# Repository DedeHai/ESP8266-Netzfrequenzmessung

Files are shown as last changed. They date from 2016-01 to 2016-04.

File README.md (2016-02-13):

# ESP8266-Netzfrequenzmessung
Measure 50Hz power grid frequency deviation using an ESP8266.

For discussions about this visit forum.netzsin.us

License:
Software under MIT license
Hardware under Creative Commons 4.0 license: CC-BY-NC-SA

#Mutatio Hardware 
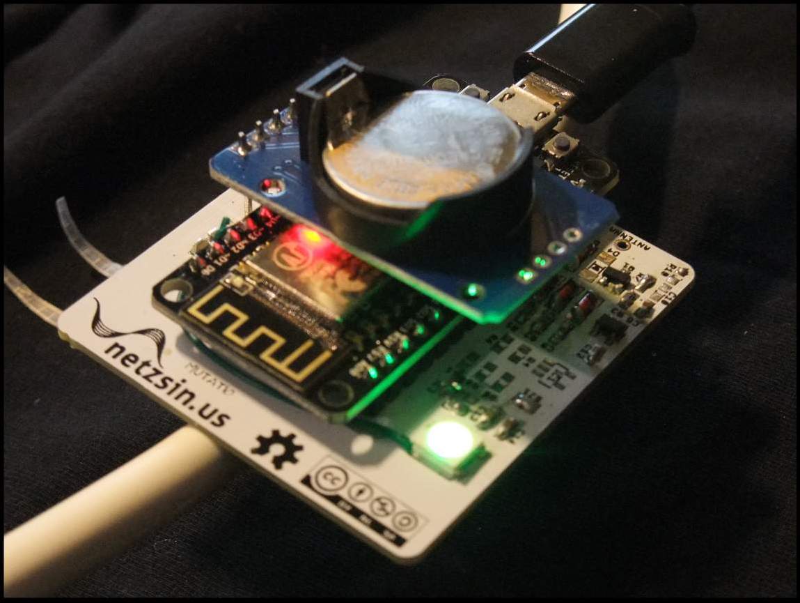
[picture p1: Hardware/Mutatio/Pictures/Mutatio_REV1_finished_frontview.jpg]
Mutatio


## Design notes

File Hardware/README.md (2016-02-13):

#Mutatio: grid frequency tracker
part of the netzsin.us project

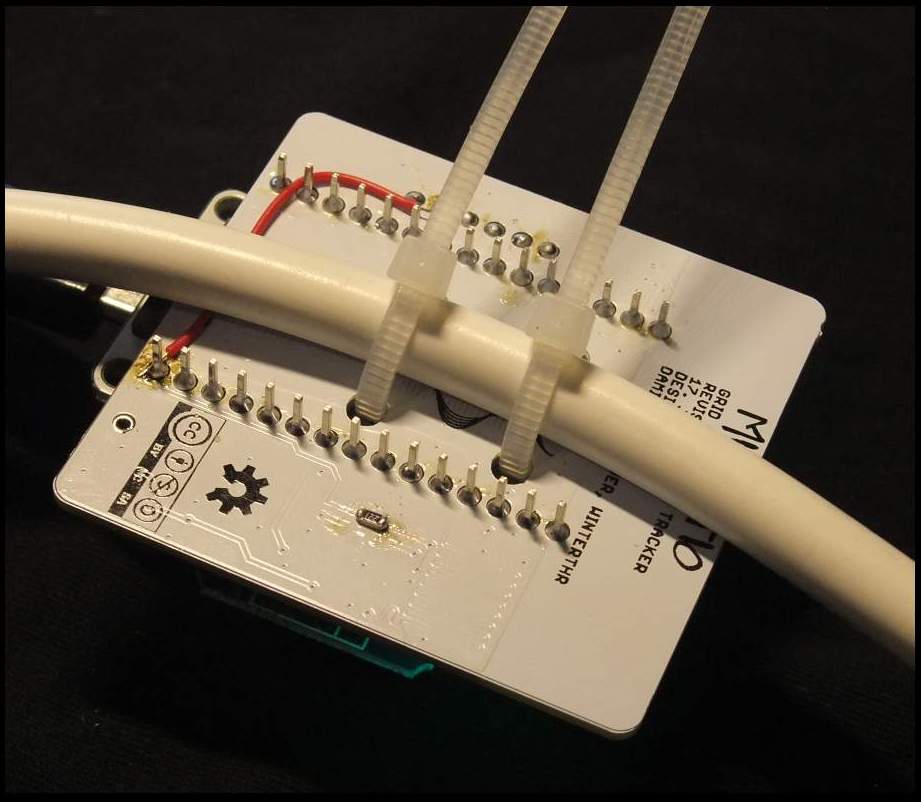
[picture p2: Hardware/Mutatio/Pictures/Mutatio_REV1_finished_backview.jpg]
backview
Mutatio |

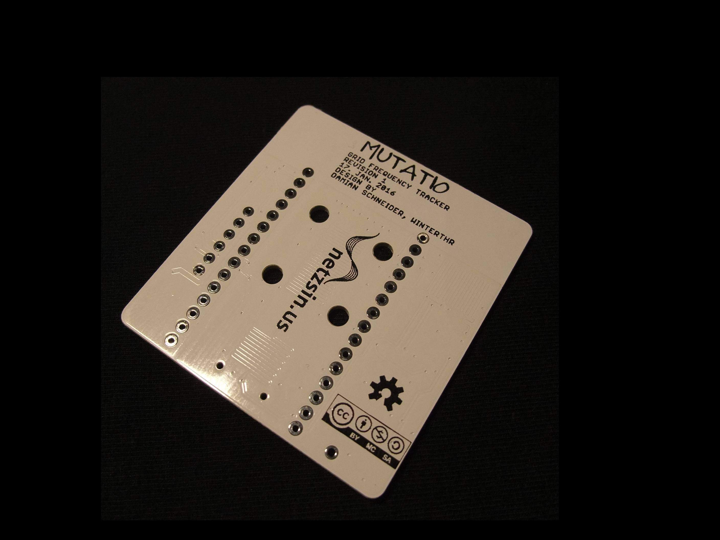
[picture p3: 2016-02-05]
Hardware/Mutatio/Pictures/Mutatio_REV1_PCB_back.jpg

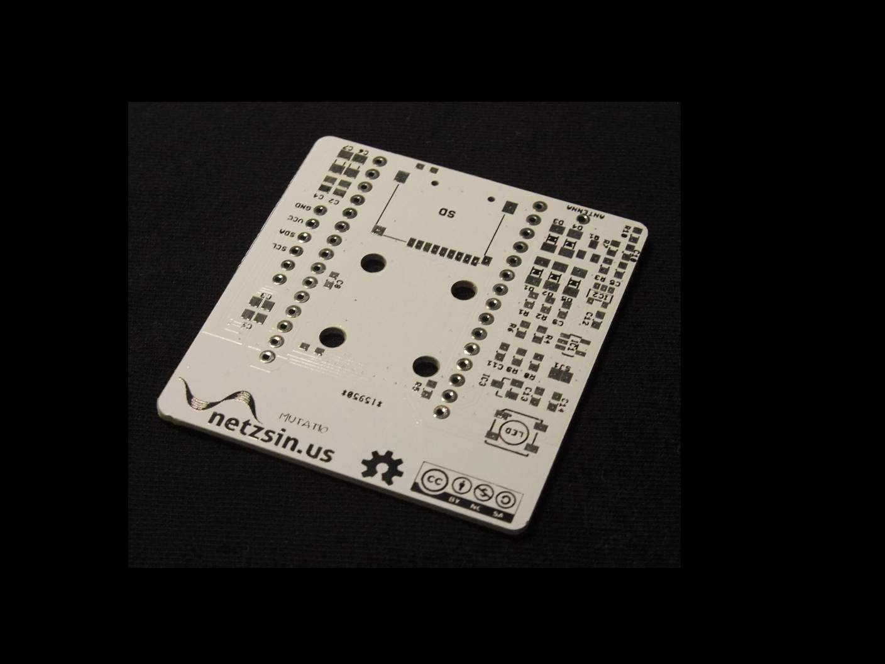
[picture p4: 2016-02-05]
Hardware/Mutatio/Pictures/Mutatio_REV1_PCB_front.jpg

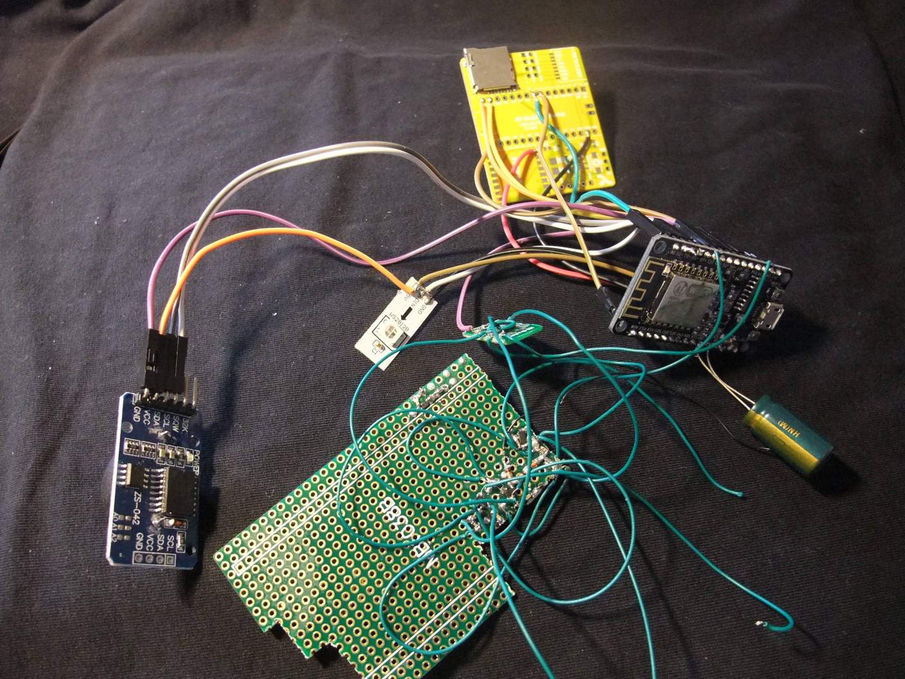
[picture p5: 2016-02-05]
Hardware/Mutatio/Pictures/prototype.jpg

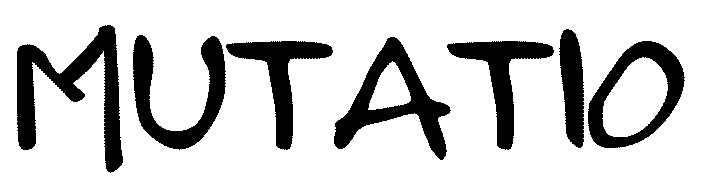
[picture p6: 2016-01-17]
Hardware/Mutatio/mutatio-font-rufscript-bw.bmp

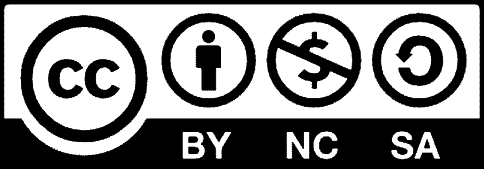
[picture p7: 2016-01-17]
Hardware/Mutatio/cc-by-nc-sa.bmp

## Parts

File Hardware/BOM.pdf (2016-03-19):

Tabelle1

Seite 1

### Mutatio BOM

Part description | Part | Cost | Source
NodeMCU (V1) | - | 6.16 € | Banggood (http://www.banggood.com/Geekcreit-Doit-NodeMcu-Lua-ESP8266-ESP-12E-WIFI-Development-Board-p-985891.htm)
RTC Module, DS3231 (Optional, track time without internet) | - | 0.90 € | Banggood (http://www.banggood.com/DS3231-AT24C32-IIC-High-Precision-Real-Time-Clock-Module-For-Arduino-p-81066.html)
NFET 2SK3018 | Q1 | 0.05 € Ebay/Aliexpress
Schmitt trigger SN74LVC1G14DBVR | IC2 | 0.07 € Ebay/Aliexpress
100uF 1206 Capacitor | C6, C7 | 0.10 € Ebay/Aliexpress
47uF 0805 Capacitor | C1, C2, C3, C4 | 0.10 € Ebay/Aliexpress
WS2812B Color LED | LED | 0.12 € Ebay/Aliexpress
22uF 0603 Capacitor | C9, C13, C14 | 0.05 € Ebay/Aliexpress
1uF 0603 Capacitor | C5 | 0.01 € Ebay/Aliexpress
100nF 0603 Capacitor | C8, C12 | 0.01 € Ebay/Aliexpress
1N4148 Diode | D1, D2, D3 | 0.02 € Ebay/Aliexpress
MicroSD Socket | - | 0.10 € Ebay/Aliexpress
51k Resistor, 0603 | R1, R2, R5 | 0.01 € Digikey
100k Resistor, 0603 | R2 | 0.01 € Digikey
1k Resistor, 0603 | R3 | 0.01 € Digikey
PCB | - | 1.40 € Elecrow
7.72 €

Additional Parts are untested (OpAmp circuit)
For datalogging, an SD card is needed (~3MB per day)

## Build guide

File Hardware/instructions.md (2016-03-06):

#Mutatio Instructions

##Uploading Firmware
Install the Arduino IDE (1.6.7 or later) and add the ESP8266 extension by following the instructions given [here](https://github.com/esp8266/Arduino). I prefer the manual cloning method over the boards manager since it works better for me. If you get any weird compiler errors, try installing manually.
The Mutatio firmware only uses two external libraries. One can be installed using the Arduino Library Manager. Install the Adafruit NeoPixel from the Manager and manually install the RTC library that can be found [here](https://github.com/Makuna/Rtc).
After installing the libraries the code should compile without errors.
**Important: the frequency signal MUST be present to upload code, seems to be a hardware bug.**

To upload the code to the Mutatio, set the board settings to:

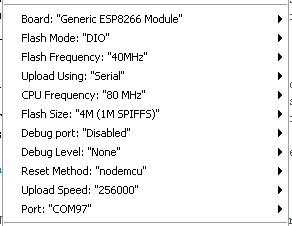
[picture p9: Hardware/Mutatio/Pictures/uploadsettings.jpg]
settings


Note: after setting up the WiFi connection also over the air uploading using WiFi (OTA update) instead of serial can be used.

##Setup
The first thing should be to get a proper signal. For testing, a 50cm (or longer) cable can be connected to the external antenna point marked 'Antenna' on the board. I use wire wrap wire but any wire will do. The Mutatio sometimes does not boot properly if there is no signal present, it is unknown why.
Open the serial port using the Arduino IDE serial monitor or any other serial monitor. I prefer 'Realterm' since it runs more stable on Windows than the Arduino monitor. Setting the Baudrate to 115200 and then resetting the board (press reset button, repeat if not booting) there should be debug output on the serial. The first two lines of gibberish are debug info from the ESP8266 chip itself and can be ignored.
Then the output should look like this:
```
sldœŸ|Œlà|Œläb|Žƒä›{›cŒcŒòggžl'nœãìcpä$slslxògàƒd„œcoâ|lŒŒ‡ÇcŒógnçd„d`˜ggl ns
››oƒŒl`r’“gƒ„d`üƒoœ                                                             
Mutatio grid frequency tracker, part of netzsin.us project                      
Reading Configuration                                                           
Configurarion Found!                                                            
connecting to MYSSID                                                            
WIFI not available: NO SSID AVAILBLE  
```
Next the Mutatio needs to be configured. This is done through the setup page. To access it, press and hold the 'Flash' button for three seconds, then release it. The LED color turns purple indicating that the accesspoint is ready. Connect your computer's WiFi to the accesspoint named 'Mutatio-XXXX' with the default password '11111111'. Open any web browser and go to '192.168.4.1'. The config page will show. Enter your routers SSID and password. As a default, DHCP is used to obtain an IP. For a static IP you can also disable DHCP and enter the connection addresses manually.
The second part of the page lets you configure the Mutatio hardware and server settings. Put checks if you are using an SD card or the real time clock (RTC).
Once the Mutatio is connected to your local WiFi the configuration page can also be accessed by entering the Muatio's local IP address: check the serial output for the IP or assign a static IP. If you have mDNS support on your computer (install apple's bonjour service) you can also access it through the address 'http://mutatio.local/'.

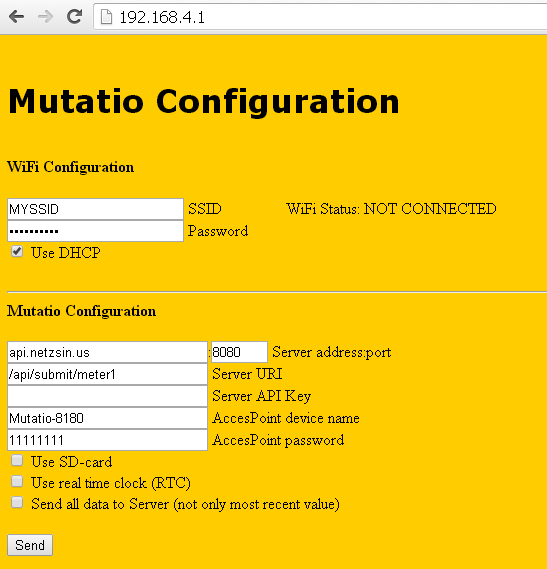
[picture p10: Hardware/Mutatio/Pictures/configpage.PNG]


##LED status colors
The LED colors indicate the status:
- **Red**: no frequency signal available: check antenna and bring a power cable close to it. If using the on board antenna: make sure the Mutatio is mounted well on the power cable as shown in the [photo](Hardware/Mutatio/Pictures/Mutatio_REV1_finished_backview.jpg).
- blinking **Yellow**: WiFi disconnected: after booting it takes up to 20s to connect
- blinking **Blue**: SD card access failed: check if SD card is present and FAT formatted 
- bright purple: access point running, 5 minute timeout 
- dim purple: OTA update in progress. Do not disconnect power or update will fail and may require re-upload through USB
- during normal operation the LED indicates the grid frequency: from blue (-60mHz) to green (0mHz) to red (+60mHz)

##Problem solving
####Frequency Signal
To check proper operation use the serial monitor. If the frequency signal is available and the time is properly set (either from the RTC or from an NTP server) there will be one measurement value displayed each second. It looks like this
```
-24.17  -24.08  75      @UTC 16:29:08.447  
```
The first number is the frequency offset calculated. The second value is the moving average over all measurement values, including all raw values. This should be very close or even identical to the first value on a good signal. The third value is a quality indicator: it shows how many measurement points out of 100 values are regarded as valid: to calculate the frequency 100 values are measured and averaged. Outliers are discarded as noise. If this number is lower than 50 the input signal is too noisy. Try a shorter antenna and bring it as close as possible to the power cable: a 15cm antenna wrapped around the cable works nicely but the best signal is obtained from the onboard antenna. Anything above 80 will give good values but if the antenna is properly tuned values above 95 can be achieved.
A good and stable power supply is *very* important. A USB from a PC or a Server is usually a good choice. A USB power supply can also work, but it needs to be of good quality. Here is a graph showing the measurement with different powersupplies:

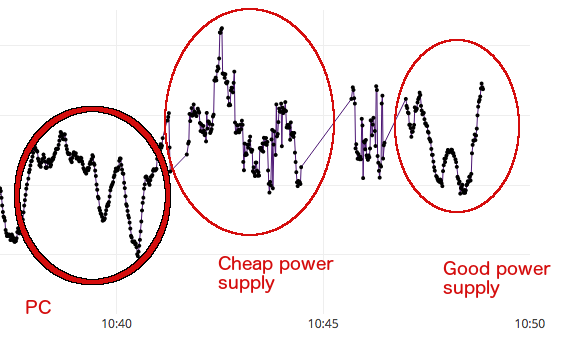
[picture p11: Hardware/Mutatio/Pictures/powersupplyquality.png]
signal vs powersupply


####Time
The time is constantly checked against a NTP server ('pool.ntp.org' by default). If the connection is too slow (average ping > 30ms) an accurate time sync is not possible. The accepted latancy can be changed in the firmware but it is not recommended since it leads to time jitter. To do so change 
````
#define ALLOWEDROUNDTRIPDELAY 30
```
in NTP_Time.h to a higher number.

To change the time server (or server pool) edit the string 
```
const char* ntpServerName = "pool.ntp.org";
```
also in in NTP_Time.h

The RTC is automatically synchronized with the NTP time every few hours. The RTC has a time keeping accuracy of ±2ppm.

####Server 
The data is sent out to a server every second. The server address (or IP) and the URI as well as the API-key can be changed on the configuration page.

There is an option on the configuration page to send out all values instead of always sending the latest one only. On a slow connection this can lead to a data jam since all unsent data is first kept in RAM and then saved to the SD card (if available, data is discarded otherwise). The Mutatio tries to sendout the oldest value first and works its way to the latest value as fast as possible. **NOTE: This mode is currently not supported by the defluxiod server software.**

In normal sending mode only the latest value is sent. If the server connection fails, the data is lost (but is still logged to the SD card if available). If the server connection always fails, check if the server address is set correctly. To see the data sent to the server and the server's response on the serial monitor, uncomment these lines in sendtoserver.h:
```
 // Serial.print(header);
 // Serial.print(jsonstring);
 
 // Serial.println(line); //uncomment this line to see servers response on serial
```

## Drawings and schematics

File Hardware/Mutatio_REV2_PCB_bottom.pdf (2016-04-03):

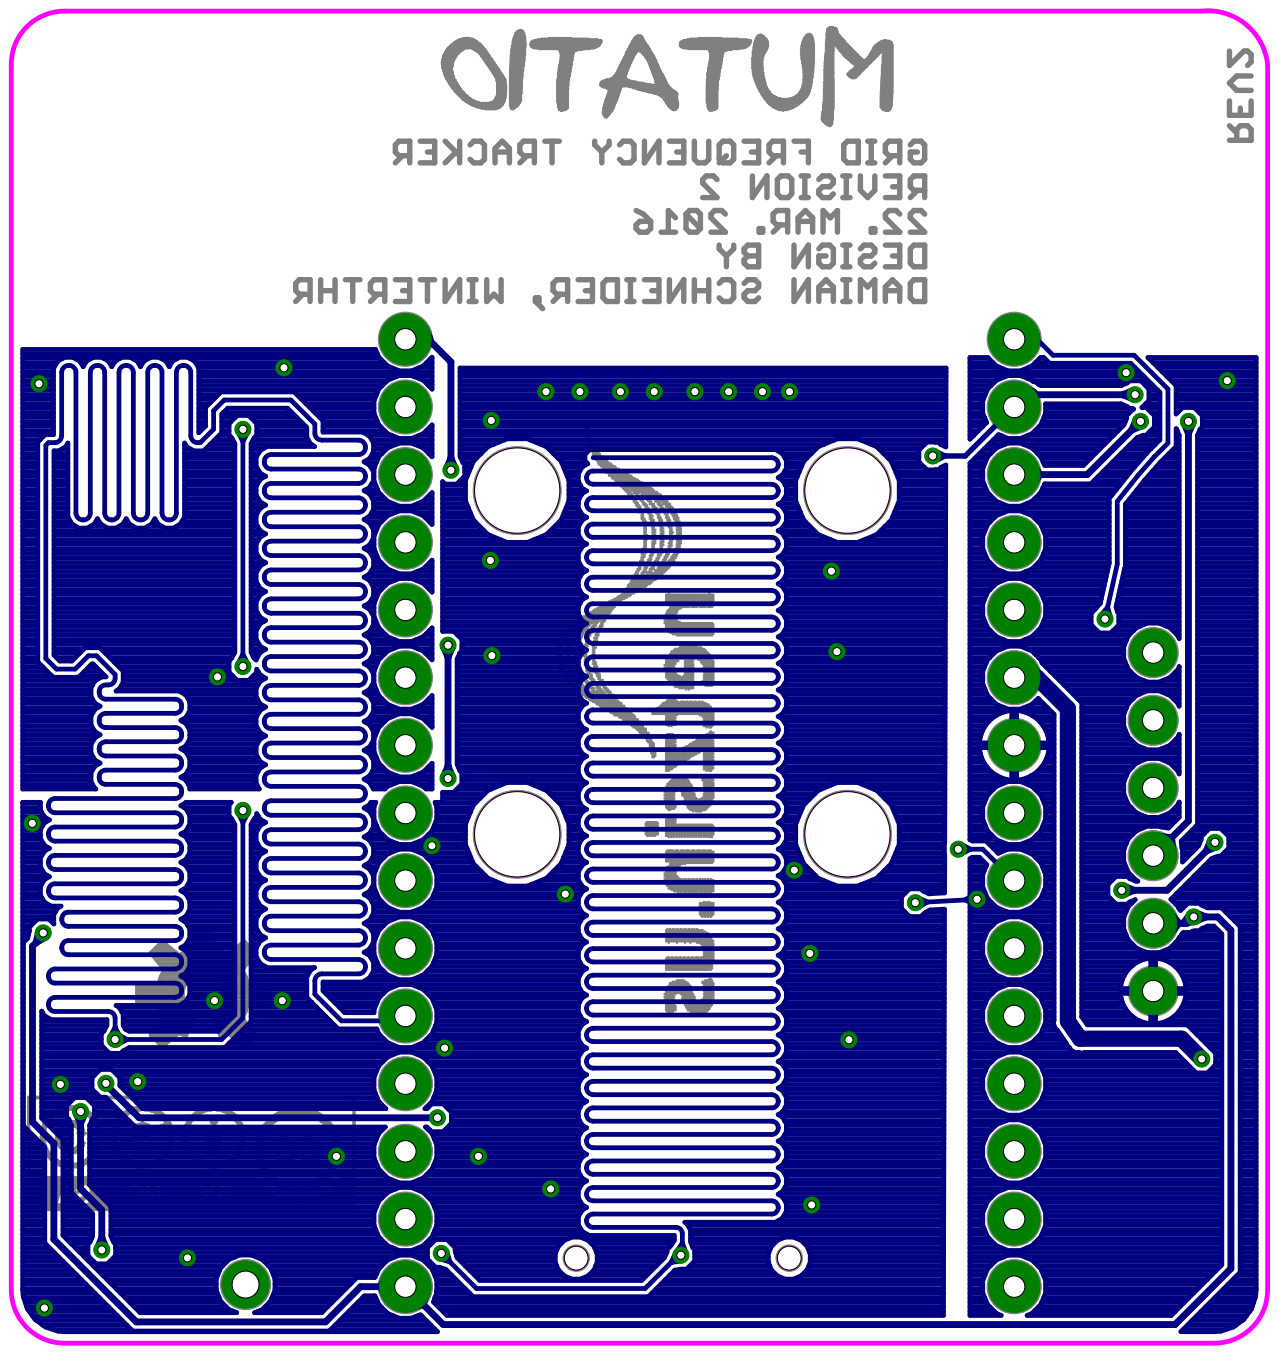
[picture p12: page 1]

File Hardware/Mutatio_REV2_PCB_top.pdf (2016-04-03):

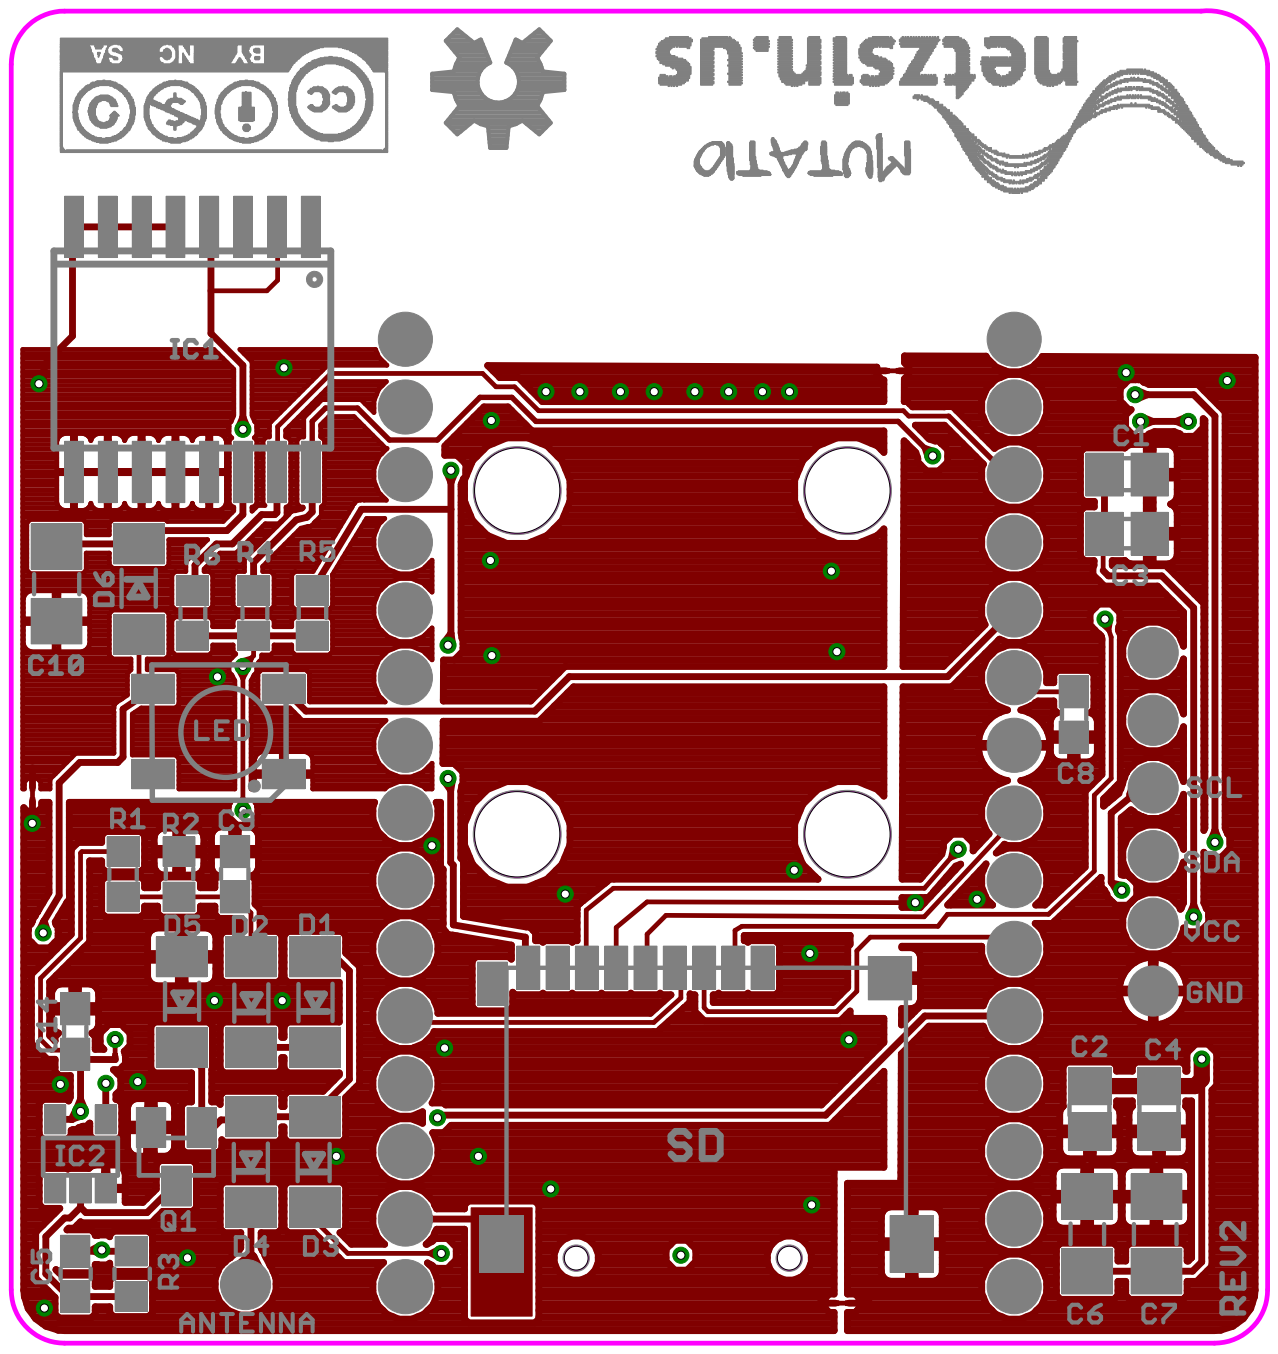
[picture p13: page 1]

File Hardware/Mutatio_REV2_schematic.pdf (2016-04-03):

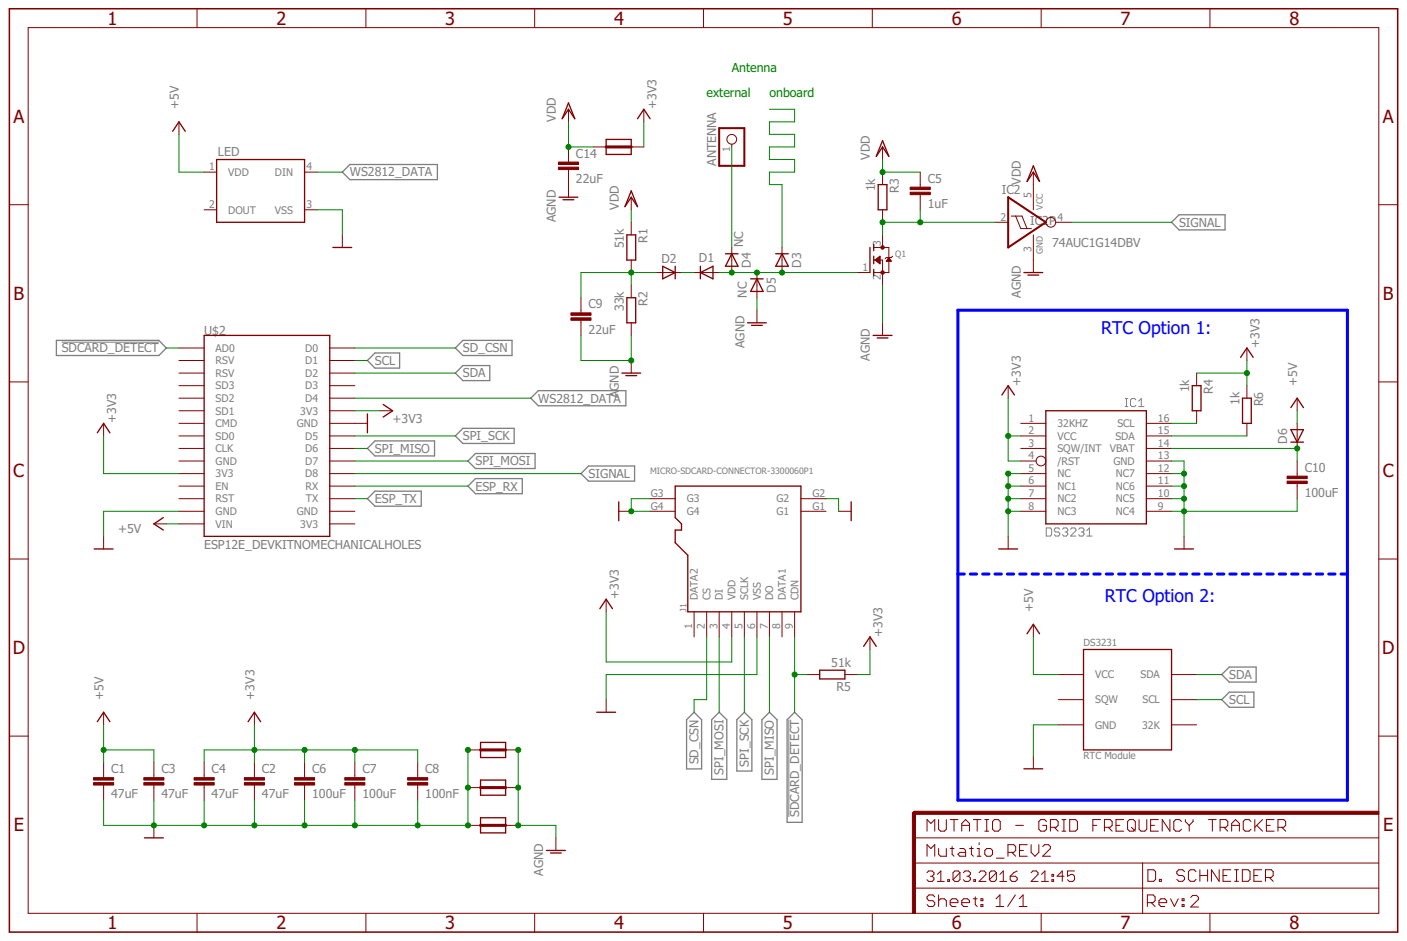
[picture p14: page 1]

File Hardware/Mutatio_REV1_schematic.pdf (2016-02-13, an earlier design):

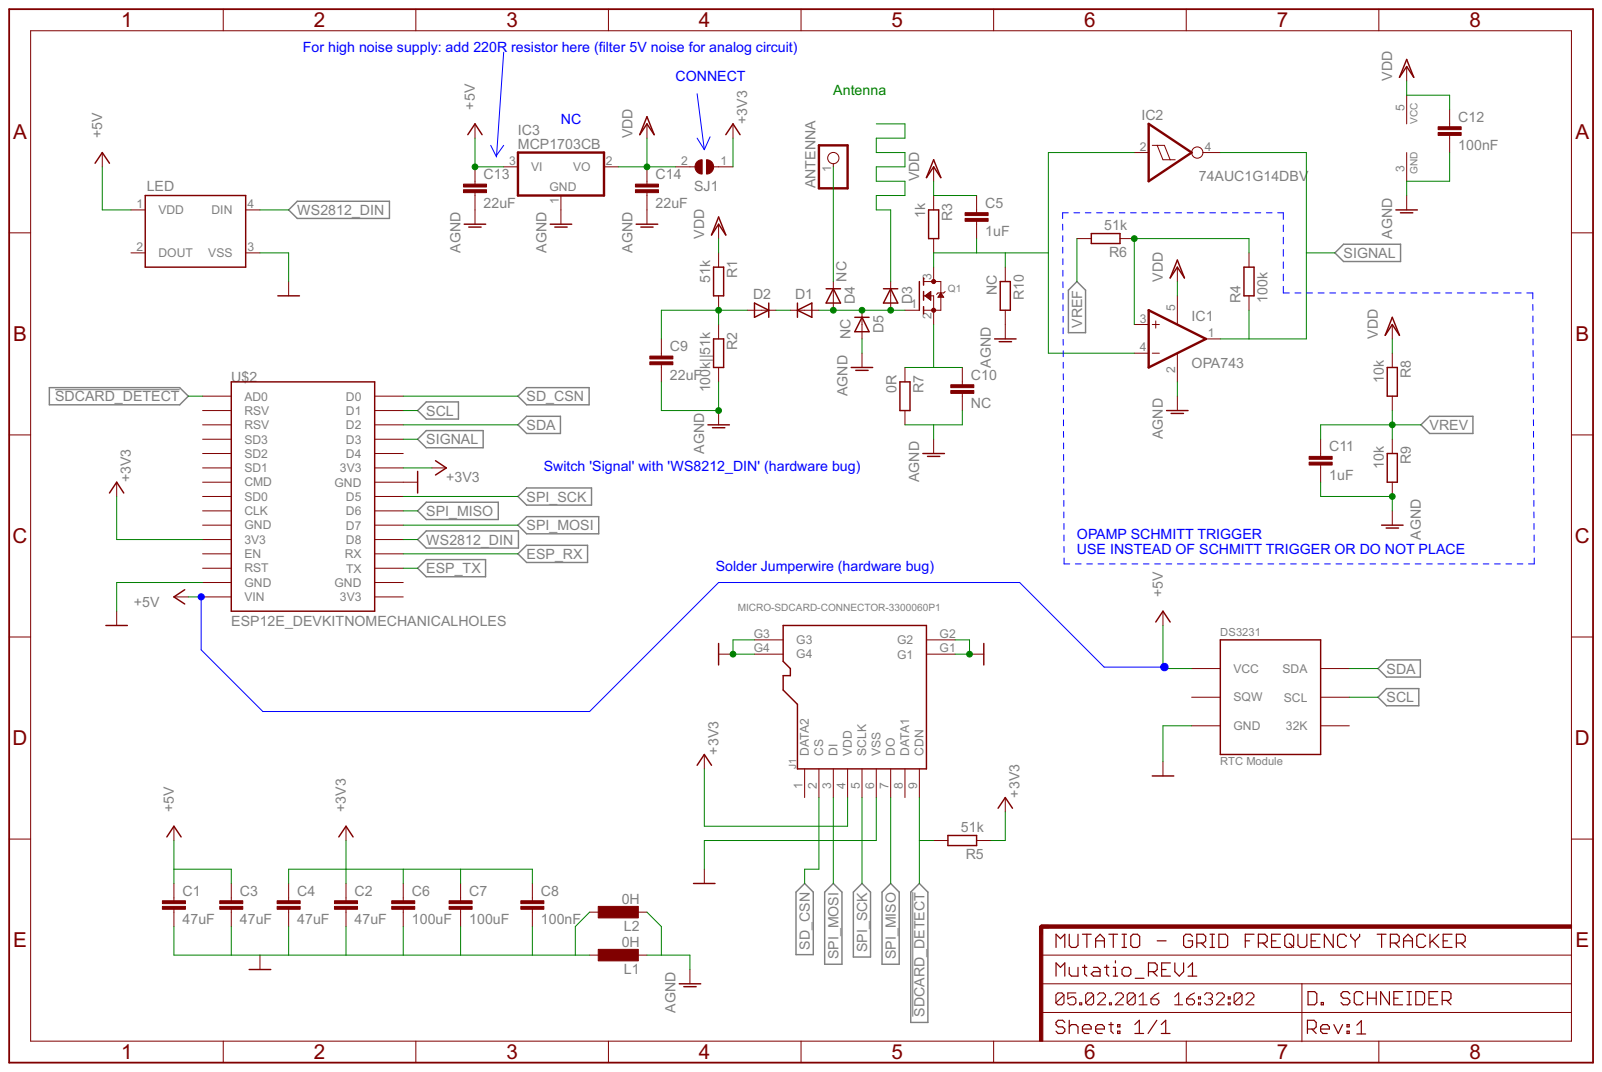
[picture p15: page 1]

Antenna For high noise supply: add 220R resistor here (filter 5V noise for analog circuit)

Switch 'Signal' with 'WS8212_DIN' (hardware bug)

OPAMP SCHMITT TRIGGER
USE INSTEAD OF SCHMITT TRIGGER OR DO NOT PLACE

Solder Jumperwire (hardware bug)

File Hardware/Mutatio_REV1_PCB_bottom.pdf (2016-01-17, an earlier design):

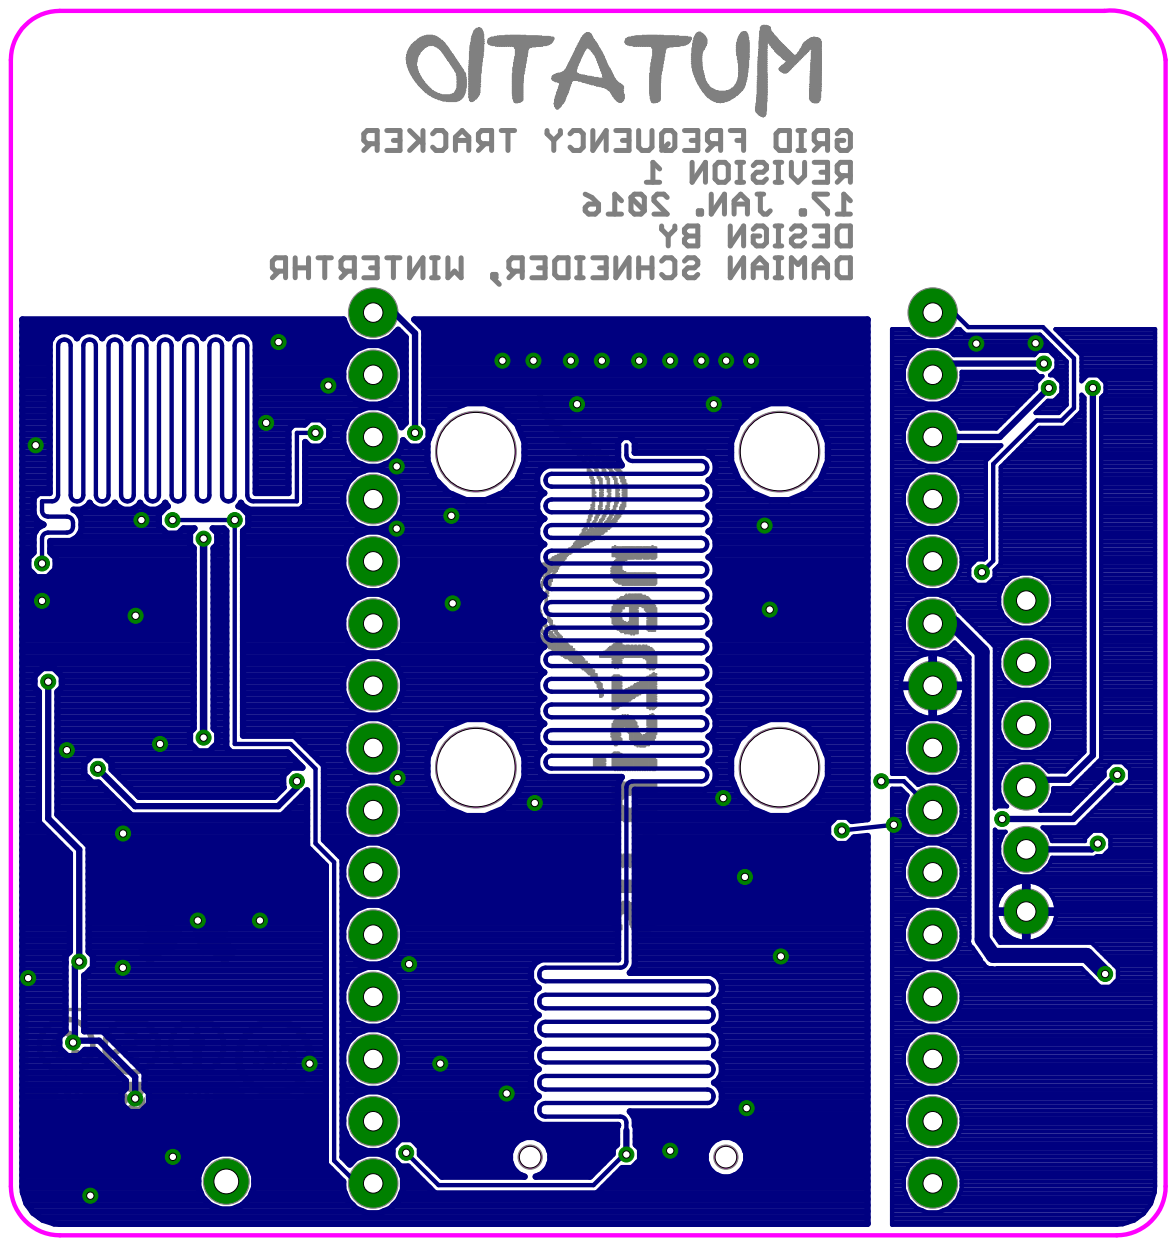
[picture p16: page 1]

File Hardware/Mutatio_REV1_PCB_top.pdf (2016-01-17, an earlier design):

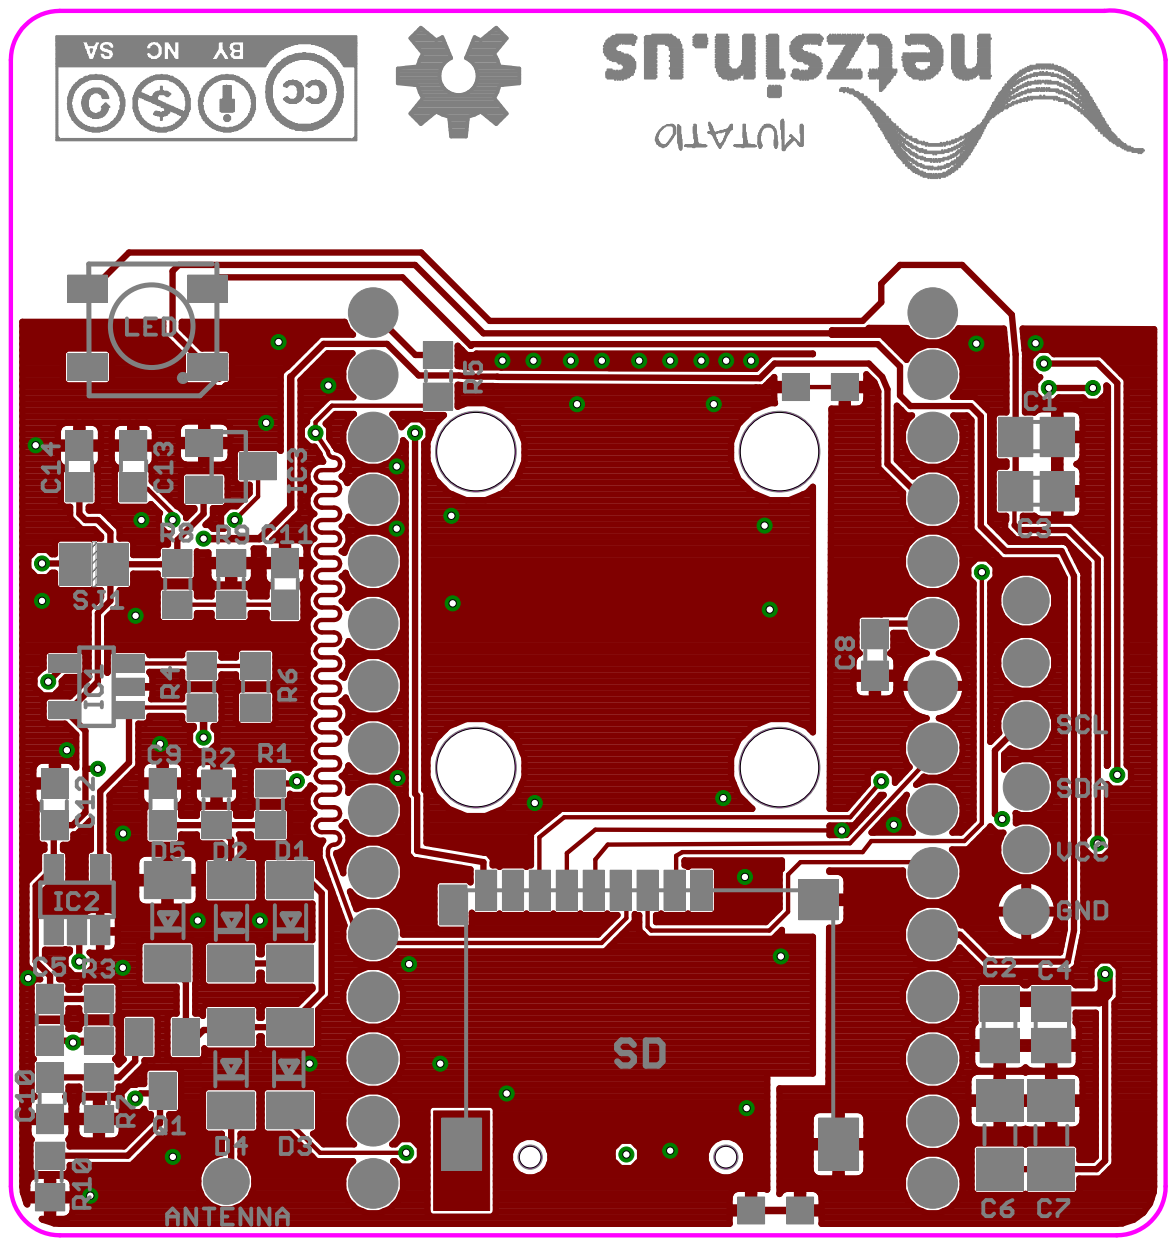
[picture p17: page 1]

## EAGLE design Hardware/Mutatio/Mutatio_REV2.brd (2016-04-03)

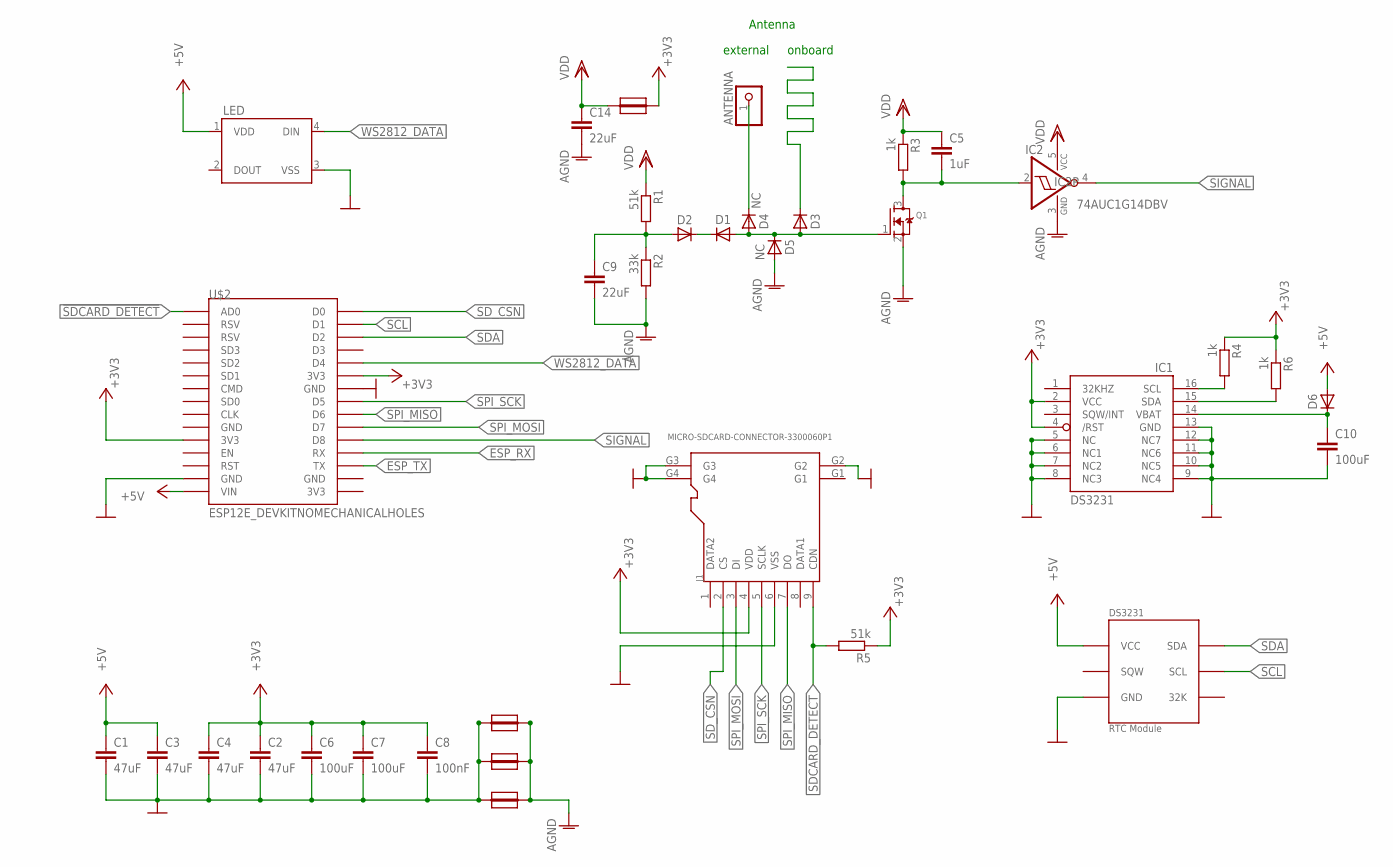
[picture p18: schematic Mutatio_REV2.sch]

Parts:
ANTENNA: PINHD-1X1CB; 1X01-CLEANBIG
C1, C2, C3, C4: 47uF; C0805
C5: 1uF; C0603
C6, C7, C10: 100uF; C1206
C8: 100nF; C0603
C9, C14: 22uF; C0603
D1, D2, D3, D6: DIODE-MINIMELF; MINIMELF
D4, D5: NC; MINIMELF
IC1: DS3231/SO; SO16W
IC2: 74AUC1G14DBV; SOT23-5
J1: MICRO-SDCARD-CONNECTOR-3300060P1; 9P-SMD-W-RING
LED: WS2812B
Q1: MOSFET-NREFLOW; SOT23
R1, R5: 51k; R0603
R2: 33k; R0603
R3, R4, R6: 1k; R0603
U$1: DS3231_MODULEBIG_CONNECTER_ONLY; DS3231_MODULE_BIGCON
U$2: ESP12E_DEVKITNOMECHANICALHOLES; ESP12E_DEVKIT_NOHOLES
U$7, U$8, U$9, U$10: SHORT

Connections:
!SDCARD_DETECT: J1.9 (CDN), R5.2, U$2.AD0
+3V3: C2.1, C4.1, C6.1, C7.1, C8.1, IC1.2 (VCC), IC1.4 (/RST), J1.4 (VDD), R4.1, R5.1, R6.1, U$2.3V3@0 (3V3), U$2.3V3@1 (3V3), U$7.P$2
+5V: C1.1, C3.1, D6.A, LED.1 (VDD), U$1.VCC@2 (VCC), U$2.VIN
AGND: C9.2, C14.2, D5.A, IC2.3 (GND), Q1.2 (S), R2.2, U$8.P$2, U$9.P$2, U$10.P$2
ANTENNA: D1.A, D3.A, D4.A, D5.C, Q1.1 (G)
BOARDANTENNA: D3.C
ESP_RX: U$2.RX
ESP_TX: U$2.TX
GND: C1.2, C2.2, C3.2, C4.2, C6.2, C7.2, C8.2, C10.2, IC1.5 (NC), IC1.6 (NC1), IC1.7 (NC2), IC1.8 (NC3), IC1.9 (NC4), IC1.10 (NC5), IC1.11 (NC6), IC1.12 (NC7), IC1.13 (GND), J1.6 (VSS), J1.G2, J1.G3, J1.G4, LED.3 (VSS), U$1.GND@2 (GND), U$2.GND@1 (GND), U$2.GND@2 (GND), U$8.P$1, U$9.P$1, U$10.P$1
unnamed: D1.C, D2.C
unnamed: ANTENNA.1, D4.C
unnamed: C5.2, IC2.2 (I), Q1.3 (D), R3.2
unnamed: C10.1, D6.C, IC1.14 (VBAT)
REF1: C9.1, D2.A, R1.2, R2.1
SCL: IC1.16 (SCL), R4.2, U$1.SCL@2 (SCL), U$2.D1
SDA: IC1.15 (SDA), R6.2, U$1.SDA@2 (SDA), U$2.D2
SD_CSN: J1.2 (CS), U$2.D0
SIGNAL: IC2.4 (O), U$2.D8
SPI_MISO: J1.7 (DO), U$2.D6
SPI_MOSI: J1.3 (DI), U$2.D7
SPI_SCK: J1.5 (SCLK), U$2.D5
VDD: C5.1, C14.1, IC2.5 (VCC), R1.1, R3.1, U$7.P$1
WS2812_DATA: LED.4 (DIN), U$2.D4

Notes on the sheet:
Antenna
onboard
external

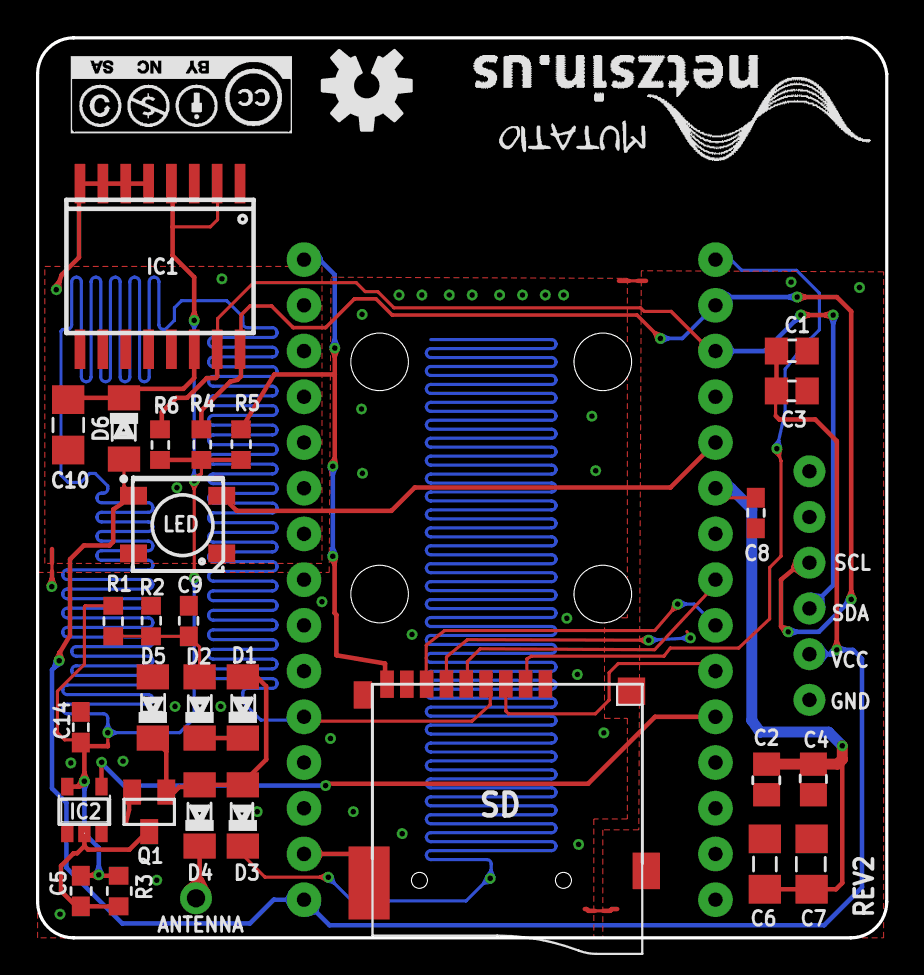
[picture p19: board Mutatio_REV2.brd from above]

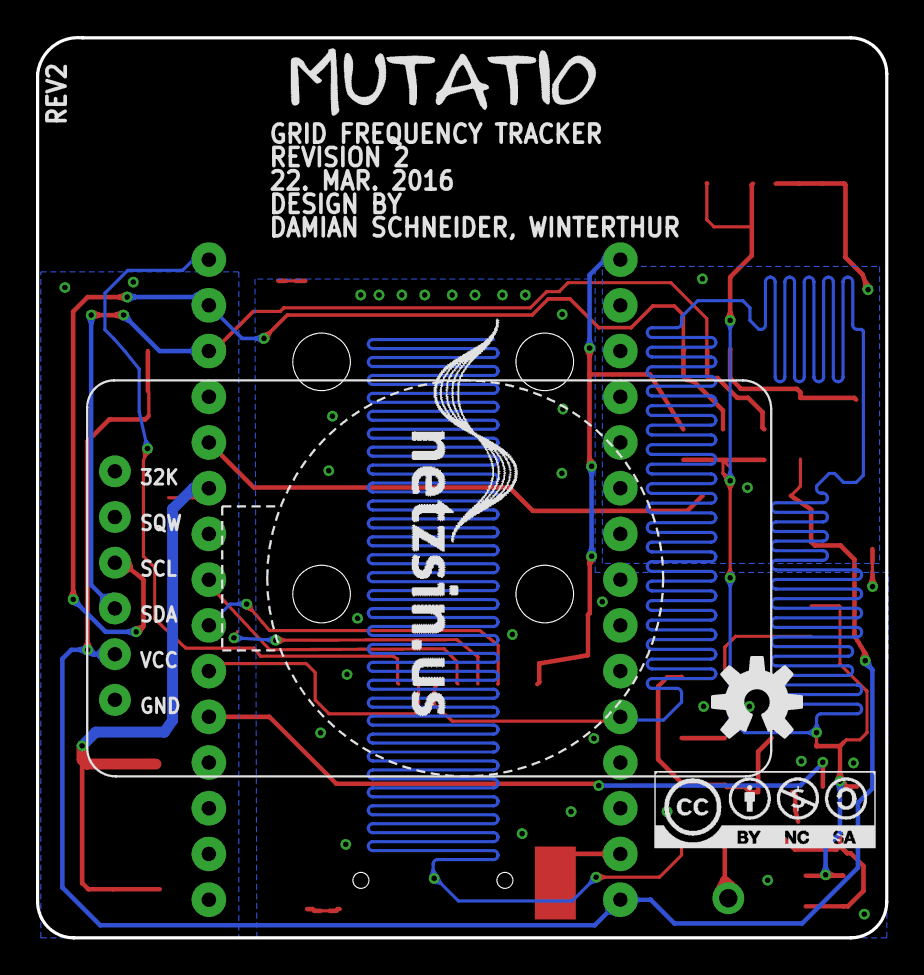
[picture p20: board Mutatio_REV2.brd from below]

Board: 2 copper layers, 47.2 x 50.0 mm, 39 parts (3 on the bottom side), 20 nets.

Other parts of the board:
U$3, U$6: OSHW-LOGO-M
U$4, U$5: CC-BY-NC-SA

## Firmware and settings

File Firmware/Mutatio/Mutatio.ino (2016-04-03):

/*important note:
   All fucntions that are called from the interrupt (including the interrupt itself and functions the functions call)
   must be put in RAM by putting the attribute ICACHE_RAM_ATTR or the system can and will crash eventually!
*/

//#define ISLANDNETWORK //if defined, higher grid fluctuations are accepted, an RTC must be present. Also, higher pings to NTP server are permitted
#define REV2 //uncomment this define if using REV2 of the Mutatio (different pin definition in global.h)

#include "Arduino.h"
#include <SPI.h>
#include <Adafruit_NeoPixel.h>
#include <ESP8266WiFi.h>
#include <WiFiClient.h>
#include <WiFiUdp.h>
#include <ESP8266WebServer.h>
#include <ArduinoOTA.h>
#include <ESP8266mDNS.h>
#include <EEPROM.h>
#include <SD.h>
#include <Wire.h> //I2C for RTC
#include "RtcDS3231.h" //RTC library: https://github.com/Makuna/Rtc
#include <EEPROM.h>
//#include <math.h>
#include "global.h"
#include "eepromhandling.h"
#include "SDcard.h"
#include "RTC_functions.h"
#include "LED.h"
#include "NTP_Time.h"
#include "thingspeak.h"
#include "interrupt.h"
#include "plotly.h"
#include "OTA_update.h"
#include "sendtoserver.h"
#include "webpage.h"
/*
   TODO:
   -find reason for memory leak in server send function (seems to have disappeared, may come back again)
*/



const double Filterconstant = 0.6; //constant for lowpass filter
double lowpassvalue = 0; //lowpass filtered frequency offset
//todo: put the clockoffset value in eeprom


void setup() {

  delay(200); //wait for power to stabilize
  Serial.begin(115200);
  memset(measurementdata, 0, sizeof(measurementdata));
  Serial.print( F("Compiled: "));
  Serial.print( F(__DATE__));
  Serial.print( F(", "));
  Serial.print( F(__TIME__));
  Serial.print( F(", "));
  Serial.println( F(__VERSION__));
  Serial.println(F("\r\nMutatio grid frequency tracker, part of netzsin.us project"));

  EEPROM.begin(256); //eeprom emulation on flash, the ESP8266 has no actual EERPOM
  if (!ReadConfig())
  {
    writeDefaultConfig();
  }

  pinMode(PIXEL_PIN, OUTPUT);
  LED.begin();
  LEDcolor.r = 100;
  LEDcolor.g = 5;
  LEDcolor.b = 1;
  LED.setPixelColor(0, LED.Color(LEDcolor.r, LEDcolor.g, LEDcolor.b));
  LED.show(); // Initialize LED color

  if (config.useRTC)
  {
    RTCinit();
  }

  wifiWatchdog = 1; //wifi not connected
  sdWatchdog = 1; //SD not initialized
  signalWatchdog = 1000; //signal not initilized

  Serial.print("connecting to ");
  Serial.println(config.ssid);
  WiFi.disconnect(true); //delete any old wifi configuration
  WiFi.mode(WIFI_STA);
  //  delay(100);
  WiFi.begin(config.ssid.c_str(), config.password.c_str());
  if (!config.useDHCP)
  {
    WiFi.config(IPAddress(config.IP[0], config.IP[1], config.IP[2], config.IP[3] ),  IPAddress(config.Gateway[0], config.Gateway[1], config.Gateway[2], config.Gateway[3] ) , IPAddress(config.Netmask[0], config.Netmask[1], config.Netmask[2], config.Netmask[3] ));
  }

  // while (WiFi.status() != WL_CONNECTED) {
  //   delay(500);
  //   Serial.print(".");
  // }
  if (config.useSDcard)
  {
    SDinit(SD_CSN_PIN);
    SDwriteLogfile("Boot");
  }


  server.on ( "/", sendPage); //send the config page
  server.on ( "/SD.htm", sendSDPage); //send the config page
  server.onNotFound(handleNotFound);//handle page not found
  server.begin(); //start webserver


  pinMode(MEASUREMENTPIN, INPUT); //is the default, just making sure
  attachInterrupt(MEASUREMENTPIN, pininterrupt, CHANGE); //trigger both rising and falling





  config.useDHCP = true;
}


//at 50.000Hz, the number of 80MHz ticks is 1600000
void loop() {

  uint8_t SDreadycounter = 0; //counts measurements ready to be written to SD card (i.e. they were already printed to Serial)
  checkButtonState(); //check state of 'FLASH' button, stat accesspoint if pressed for some time
  updateLED();


  //check if there is old data avialable on the SD card and send it to server
  if (WiFi.status() == WL_CONNECTED)
  {
    if (wifiWatchdog > 0) //wifi was not connected before, print some info, init some wifi related stuff
    {
      Serial.println("");
      Serial.println("WiFi connected");
      Serial.print("IP address: ");
      Serial.println(WiFi.localIP());
      wifiWatchdog = 0; //connected to wifi
      timeManager(1); //force time update from NTP server
      initOTAupdate();
      SDwriteLogfile("WIFI connected");

      // plotly_init(true); //!!! comment this line if not using plotly server

    }
    ArduinoOTA.handle();

    if (unsentSDData) //unsentSDData is only set if config.sendAllData is enabled
    {
      sendSDdataToServer();
    }
  }
  else
  {
    if (wifiWatchdog == 0) //wifi was connected before
    {
      SDwriteLogfile("WIFI disconnected");
      WiFi.begin(config.ssid.c_str(), config.password.c_str());
      if (!config.useDHCP)
      {
        WiFi.config(IPAddress(config.IP[0], config.IP[1], config.IP[2], config.IP[3] ),  IPAddress(config.Gateway[0], config.Gateway[1], config.Gateway[2], config.Gateway[3] ) , IPAddress(config.Netmask[0], config.Netmask[1], config.Netmask[2], config.Netmask[3] ));
      }
      String state;
      if (WiFi.status() == 0) state = "Idle";
      else if (WiFi.status() == 1) state = "NO SSID AVAILBLE";
      else if (WiFi.status() == 2) state = "SCAN COMPLETED";
      else if (WiFi.status() == 3) state = "CONNECTED";
      else if (WiFi.status() == 4) state = "CONNECT FAILED";
      else if (WiFi.status() == 5) state = "CONNECTION LOST";
      else if (WiFi.status() == 6) state = "DISCONNECTED";
      Serial.println("WIFI not available: " + state);
    }
    wifiWatchdog++; //disconnected from wifi
    if (wifiWatchdog > 10000) wifiWatchdog = 0; //try to reconnect to WiFi every ~10 seconds
    delay(1);
  }

  if (issampling == false) ////wait for interrupt to capture a measurement and write data to the buffer
  {
    uint16_t i = datareadindex;
    uint16_t j;
    uint8_t thingspeakFailed = 0;
    uint8_t serverFailed = 0;
    uint16_t latestindex = datareadindex;

    for (j = 0; j < MEASUREMENTVALUES; j++)
    {
      if (measurementdata[i].flag > 0 && ((measurementdata[i].flag & 0x02) == 0)) //not yet printed
      {
        latestindex = i;
        measurementdata[i].flag |= 0x02; //data printed, can now be saved to SD
        printMeasurement(i);

        if (sdWatchdog > 0) //not using SD or SD failed
        {
          datareadindex = i; //update the read index (is usually done in SD function after saving the value)
        }

        //make LED color green if 50.0Hz, red if too high, blue if too low
        int16_t colorindicator = measurementdata[i].data / 70;
        if (colorindicator > 85) colorindicator = 85;
        else if (colorindicator < -85) colorindicator = -85;
        LEDcolor = hsv_to_rgb(85 - colorindicator, 255, 20);

        if (config.sendAllData)
        {
          if (unsentSDData == 0 && measurementdata[i].flag > 0 && (measurementdata[i].flag & 0x08) == 0 && WiFi.status() == WL_CONNECTED && serverFailed == 0) //not yet sent and we have a wifi connection
          {
            if (sendMeasurementToServer(measurementdata[i]) == 0) //send successful?
            {
              measurementdata[latestindex].flag |= 0x08; //mark as sent out
            }
            else
            {
              serverFailed = 1; //try again next time
            }
          }
        }


        //thingspeak sendout & heap display for debugging
        /*
                if ((millis() - thingspeakTime > 15000) && (thingspeakFailed == 0) && WiFi.status() == WL_CONNECTED) //send this one out to thingspeak
                {
                  // thingspeakFailed = updateThingspeak(measurementdata[i].data);
                  Serial.print("Free heap:");
                  Serial.println(ESP.getFreeHeap(), DEC); //debug: check for memory leaks
                  thingspeakTime = millis();
                  SDwriteLogfile("Test");
                }
        */



      }
      else if (measurementdata[i].flag > 1 && ((measurementdata[i].flag & 0x04) == 0) ) SDreadycounter++; //count number of measurements ready to be written to SD



      i++;
      if (i >= (MEASUREMENTVALUES)) i = 0; //continue at beginning if end of buffer reached
    }

    //send only the latest measurement (put in above for loop to send them all, change latestindex to i
    if (measurementdata[latestindex].flag > 0 && (measurementdata[latestindex].flag & 0x08) == 0 && WiFi.status() == WL_CONNECTED && serverFailed == 0 && !config.sendAllData) //not yet sent and we have a wifi connection
    {
      //plotly_plot(measurementdata[latestindex]);

      if (sendMeasurementToServer(measurementdata[latestindex]) == 0) //send successful?
      {
        measurementdata[latestindex].flag |= 0x08; //mark as sent out
      }
    }

    issampling = true;
  }


  if (config.useSDcard)
  {
    if (SD_initialized) //card is initialized //note: tried to add analogRead here, it makes the wifi disconnect very frequently, seems to be a known issue
    {
      if ((MEASUREMENTVALUES - SDreadycounter) < 70) //buffer is getting full, better save it to SD
      {
        if (SDwriteMeasurements(SDreadycounter) != 0) //write failed, re-initialize the SD card
        {
          if (SDinit(SD_CSN_PIN) != 0)
          {
            yield();
            Serial.println(F("PANIC, NO SD CARD AVAILABLE!"));
            sdWatchdog = 1;
            //todo: inform the user by email, sms or fax
          }
        }
      }
    }
    else if (config.useSDcard && sdWatchdog == 1)
    {
      SDinit(SD_CSN_PIN);
    }
    else sdWatchdog++;
  }
  timeManager(0);
  yield();
  server.handleClient();

  yield();
  signalWatchdog++;
}

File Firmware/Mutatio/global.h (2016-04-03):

//if CPU clock is running too slow (i.e. lower than 80MHz) the internal time will also run slow and the time offset to the NTP server will become negative
#define FCPU 80000000UL //CPU clock frequency (will be corrected with clock offset in calculation)
#define NUMBEROFCAPTURES 100 //number of values to capture from frequency pin input before generating a measurement (100 per second)
#define MEASUREMENTVALUES 120 //array with this many values is created (255 max!)
#ifdef REV2
#define MEASUREMENTPIN 15 //pin which is used as clock input
#define PIXEL_PIN 2
#else
#define MEASUREMENTPIN 15 //pin which is used as clock input
#define PIXEL_PIN 0
#endif
#define ACCESSPOINTIMEOUT 300000 //timeout for accesspoint mode


RtcDS3231 RTC; //DS3231 RTC clock on I2C
ESP8266WebServer server(80); // The Webserver
WiFiClient client;
Adafruit_NeoPixel LED = Adafruit_NeoPixel(1, PIXEL_PIN, NEO_GRB + NEO_KHZ800);

void timeManager(uint8_t forceTimeSync); //function prototype

struct Config {
  String ssid; //32 bytes maximum
  String password; //32 bytes maximum
  String APIkey;
  String DeviceName;  //32 bytes maximum, name for access point
  String DevicePW;  //32 bytes maximum, password for access point
  uint8_t IP[4];
  uint8_t Netmask[4];
  uint8_t Gateway[4];
  bool useDHCP;
  bool useSDcard; //make use of the SD card
  bool useRTC; //make use of the RTC
  bool sendAllData; //send all data to server, not only the latest value, also sends SD backed up data if useSDcard is set
  int16_t FCPUerror;//error in CPU clock =  (offset in [ms]) * FCPU / (time in [ms] over which offset was measured)  -> clockoffset is negative if time offset is negative
  String serveraddress; //address string (or ip string) of server to send the data to
  uint16_t serverport;
  String serverURI; //URI of the server to stream to, for example "/api/submit/meter1" 31 chars maximum
  
} config;


struct Measurement {
  uint32_t Timestamp;
  int16_t milliseconds; //millisecond offset of measurement to timestamp
  int32_t data;
  uint8_t quality; //number of good datapoints used in this measurement value
  uint8_t flag; //flag showing status of the data, binary encoded: first bit is valid data, second bit is serial printed, third bit is written to SD, fourth bit is sent out to server
  int32_t lowpassfilteredmeasurement; //!!! for debug
};

struct timeStruct {
  uint32_t NTPtime; //seconds of time since 1900
  int16_t milliseconds; //fraction of seconds of time in milliseconds (can become negative! but only -5 milliseconds max)
  uint32_t millistimestamp; //millis() time when the time was last synchronized
};


timeStruct localTime; //the global local time variables holding current NTP time
bool localTimeValid = false; //is true once the local time contains valid time data (to prevent corrupted measurement data)
bool RTCTimeValid = false; //is set true after setting the RTC
unsigned long thingspeakTime = 0; //used in main loop to control when data is sent out (must not do it faster than every 15 seconds)
unsigned long plotlyTime = 0; //used in main loop to control when data is sent out (must not do it faster than every 15 seconds)
uint8_t SD_initialized = 0;
uint8_t RTCsynctime = 0; //keep track of when to sync the RTC (once every few hours is enough)

uint16_t wifiWatchdog;
uint16_t sdWatchdog;
uint16_t signalWatchdog;

volatile uint8_t toggle;
volatile uint32_t timekeeper = 0;
volatile uint8_t interruptnoisedetector = 0;
volatile uint32_t capturetime[NUMBEROFCAPTURES];
volatile uint32_t lastcapture = 0;
volatile uint16_t datareadindex = 0; //index in data measurement array that has to be read next when writing to SD card or sending to server (managed in SD card writing)
volatile boolean issampling = true;
int measurementindex = 0;
uint32_t cyclecountMillistimestamp;
uint32_t cyclecountatTimestamp;
uint8_t unsentSDData = 0; //unsent data available on SD card?
String unsentFilename = "unsent.txt";
uint8_t APactive = 0;
float localtimeoffset = 0; //low pass filtered offset in [ms] of local time compared to NTP time
uint16_t NTPfailcounter = 0;

Measurement measurementdata[MEASUREMENTVALUES];

//function returns the same value as millis() but can be fully put in RAM for no-crash interrupt access
//the values need to be updated at least every 60 seconds
uint32_t ICACHE_RAM_ATTR getMillisfromCycleCount(void) //assumes that the timestamp is updated before the CycleCounter overflows more than once
{
  uint32_t microseconds = ((ESP.getCycleCount() - cyclecountatTimestamp) / (FCPU / 1000000)); //80 cpu ticks per microsecond @ 80MHz
  if ((microseconds % 1000) > 500) microseconds += 500;
  return cyclecountMillistimestamp + (microseconds / 1000);
}

void setCyclecountmillis(void)
{
  noInterrupts();
  cyclecountatTimestamp = ESP.getCycleCount();
  cyclecountMillistimestamp = millis();
  interrupts();
}

void ICACHE_RAM_ATTR getNowTime(timeStruct* t)
{
  uint32_t milliseconds = getMillisfromCycleCount();
  uint64_t nowmilliseconds = (uint64_t)localTime.NTPtime * 1000 + (localTime.milliseconds  - (int)localtimeoffset) + (milliseconds - localTime.millistimestamp);
  t->NTPtime = nowmilliseconds / 1000;
  t->milliseconds =  nowmilliseconds - (uint64_t)t->NTPtime * 1000;
  t->millistimestamp = milliseconds;
}

void ICACHE_RAM_ATTR writeMeasurement(int32_t value, uint8_t gooddatapoints,  int32_t lowpassvalue) //!!!lowpassvalue for debug
{

  if (localTimeValid) //can only write the value if local time is set
  {
    timeStruct nowTime;
    getNowTime(&nowTime);
    measurementdata[measurementindex].data = value;
    measurementdata[measurementindex].quality = gooddatapoints;
    measurementdata[measurementindex].Timestamp = nowTime.NTPtime;
    measurementdata[measurementindex].milliseconds = nowTime.milliseconds;
    if ( measurementdata[measurementindex].milliseconds < 0)
    {
      measurementdata[measurementindex].Timestamp--;
      measurementdata[measurementindex].milliseconds += 1000;
    }
    else if (measurementdata[measurementindex].milliseconds >= 1000)
    {
      measurementdata[measurementindex].Timestamp++;
      measurementdata[measurementindex].milliseconds -= 1000;
    }
    measurementdata[measurementindex].flag = 1;
    measurementdata[measurementindex].lowpassfilteredmeasurement = lowpassvalue; //!!!for debug
    measurementindex++;
    if (measurementindex >= MEASUREMENTVALUES) measurementindex = 0;
  }
}
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

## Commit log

2016-01-17 Added SD card, RGB LED and RTC support
    -SD card support added for saving measurement data
    -RGB led for status and frequency deviation
    -Real Time Clock to track time when server is not available (not very
    accurate yet, a bug?)
    [LED.h, NTP_Time.h, SDcard.h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]
2016-01-17 Mutatio Hardware initial commit
    PCB design for the Mutatio hardware
    [Mutatio_REV1.brd, Mutatio_REV1.sch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]
2016-01-30 Big update, added LED, OTA update, changed noise detection algorithm, added RTC synchronization and server sync functionality
    [Mutatio_REV1.GBL, Mutatio_REV1.GBO, Mutatio_REV1.GBS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]
2016-01-31 Added eeprom support for configuration Added a configuration webpage Added Accesppoint functionality fixed some bugs
    [LED.h, Mutatio.ino, NTP_Time.h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]
2016-02-05 Added bug description and changed component values
    [Mutatio_REV1.brd, Mutatio_REV1.sch]
2016-02-05 Added BOM
    [BOM.ods]
2016-02-07 -commented out all the thingspeak test stuff -added sendout server configuration handling to functions and eeprom (address, port and URI) -handle config.sendAllData correctly -add non-DHCP control to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
    [Mutatio.ino, NTP_Time.h, SDcard.h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]
2016-02-09 bugfixes in LED and FCPU measurement
    [LED.h, NTP_Time.h, xxchangelog.ino]
2016-02-12 bugfix in SD error blink and FCPU measurement
    [NTP_Time.h, xxchangelog.ino]
2016-02-19 bugfixes and improvements in plotly sending
    [Mutatio.ino, NTP_Time.h, SDcard.h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]
2016-03-11 bugfix in measurement overflow
    [NTP_Time.h, global.h]
2016-03-19 error in BOM
    [BOM.ods]
2016-03-21 working on REV2 board
    [Mutatio_REV2.brd, Mutatio_REV2.sch]
2016-03-22 Revision2 work in progress
    [Mutatio_REV2.sch]
2016-03-25 finished revision 2
    [Mutatio_REV2.brd, Mutatio_REV2.sch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]
2016-04-03 Updated REV2 hardware
    changed the Signal and the LED pin so upload and bootup works properly
    [Mutatio_REV2.brd, Mutatio_REV2.sch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]

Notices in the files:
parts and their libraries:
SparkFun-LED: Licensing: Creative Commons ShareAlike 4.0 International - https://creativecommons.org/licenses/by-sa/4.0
